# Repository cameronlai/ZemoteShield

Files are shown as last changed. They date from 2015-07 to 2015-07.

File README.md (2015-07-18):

# ZemoteShield
Zemote Shield for Zemote Universal Remote Control (on Arduino Uno and Nano)

This project, and all of its design files (including the layout), is licensed under the Creative Commons Attribution-ShareAlike 3.0 Unported license.

Related pages
- Project page: http://cameronlai.com/zemote/
- Zemote Firmware: https://github.com/cameronlai/ZemoteFirmware
- Zemote Host: https://github.com/cameronlai/ZemoteHost

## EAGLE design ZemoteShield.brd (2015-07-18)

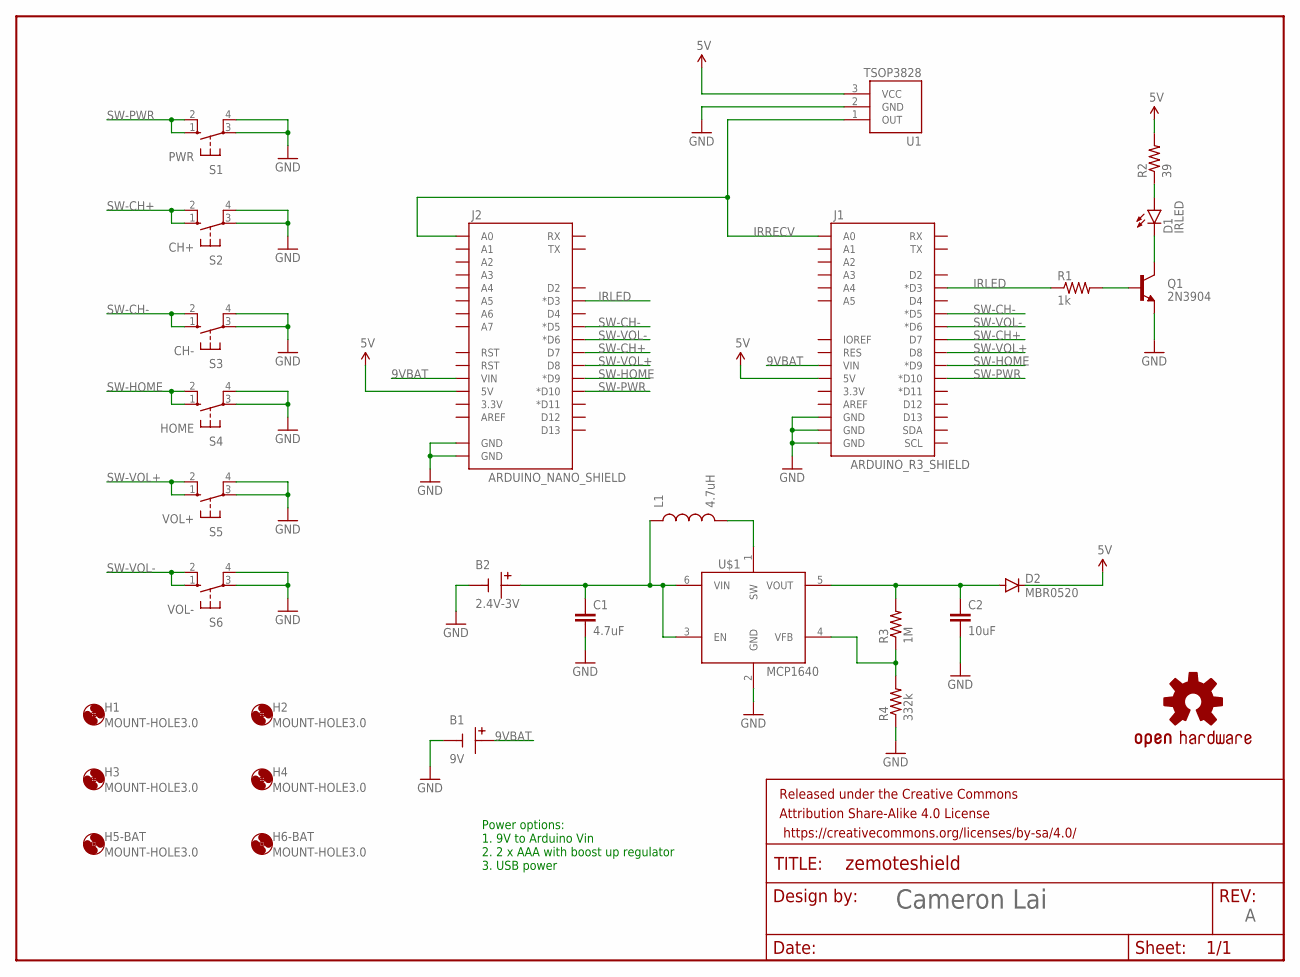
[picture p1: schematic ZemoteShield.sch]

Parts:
B1: 9V; BATTERY-2PIN-CON
B2: 2.4V-3V; BATTERY-2PIN-CON
C1: 4.7uF; 0603-CAP
C2: 10uF; 0805
D1: IRLED; LED5MM
D2: MBR0520; SOD-123
FRAME1: ZemoteShield; DUMMY
H1, H2, H3, H4, H5-BAT, H6-BAT: MOUNT-HOLE3.0; 3,0
J1: ARDUINO_R3_SHIELD; UNO_R3_SHIELD
J2: ARDUINO_NANO_SHIELD; NANO_SHIELD
L1: 4.7uH; 1210
LOGO1: OSHW-LOGOL; OSHW-LOGO-L
Q1: 2N3904; TO-92
R1: 1k; AXIAL-0.4
R2: 39; AXIAL-0.6
R3: 1M; 0603-RES
R4: 332k; 0603-RES
S1: PWR; B3F-10XX
S2: CH+; B3F-10XX
S3: CH-; B3F-10XX
S4: HOME; B3F-10XX
S5: VOL+; B3F-10XX
S6: VOL-; B3F-10XX
U1: TSOP3828; BRM-2508
U$1: MCP1640; SOT23-6

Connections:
5V: D2.C, J1.5V, J2.5V, R2.P$2 (2), U1.3 (VCC)
9VBAT: B1.POS, J1.VIN, J2.VIN
AAABAT: B2.POS, C1.1, L1.1, U$1.3 (EN), U$1.6 (VIN)
GND: B1.NEG, B2.NEG, C1.2, C2.2, J1.GND@0 (GND), J1.GND@1 (GND), J1.GND@2 (GND), J2.GND@0 (GND), J2.GND@1 (GND), Q1.1 (E), R4.1, S1.3, S1.4 (P1), S2.3, S2.4 (P1), S3.3, S3.4 (P1), S4.3, S4.4 (P1), S5.3, S5.4 (P1), S6.3, S6.4 (P1), U1.2 (GND), U$1.2 (GND)
IRLED: J1.D3 (*D3), J2.D3 (*D3), R1.P$1 (1)
IRRECV: J1.A0, J2.A0, U1.1 (OUT)
unnamed: D1.K (C), Q1.3 (C)
unnamed: Q1.2 (B), R1.P$2 (2)
unnamed: D1.A, R2.P$1 (1)
unnamed: L1.2, U$1.1 (SW)
unnamed: C2.1, D2.A, R3.2, U$1.5 (VOUT)
unnamed: R3.1, R4.2, U$1.4 (VFB)
SW-CH+: J1.D7, J2.D7, S2.1 (S), S2.2 (S1)
SW-CH-: J1.D5 (*D5), J2.D5 (*D5), S3.1 (S), S3.2 (S1)
SW-HOME: J1.D9 (*D9), J2.D9 (*D9), S4.1 (S), S4.2 (S1)
SW-PWR: J1.D10 (*D10), J2.D10 (*D10), S1.1 (S), S1.2 (S1)
SW-VOL+: J1.D8, J2.D8, S5.1 (S), S5.2 (S1)
SW-VOL-: J1.D6 (*D6), J2.D6 (*D6), S6.1 (S), S6.2 (S1)

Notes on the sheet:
Power options: 1. 9V to Arduino Vin 2. 2 x AAA with boost up regulator 3. USB power

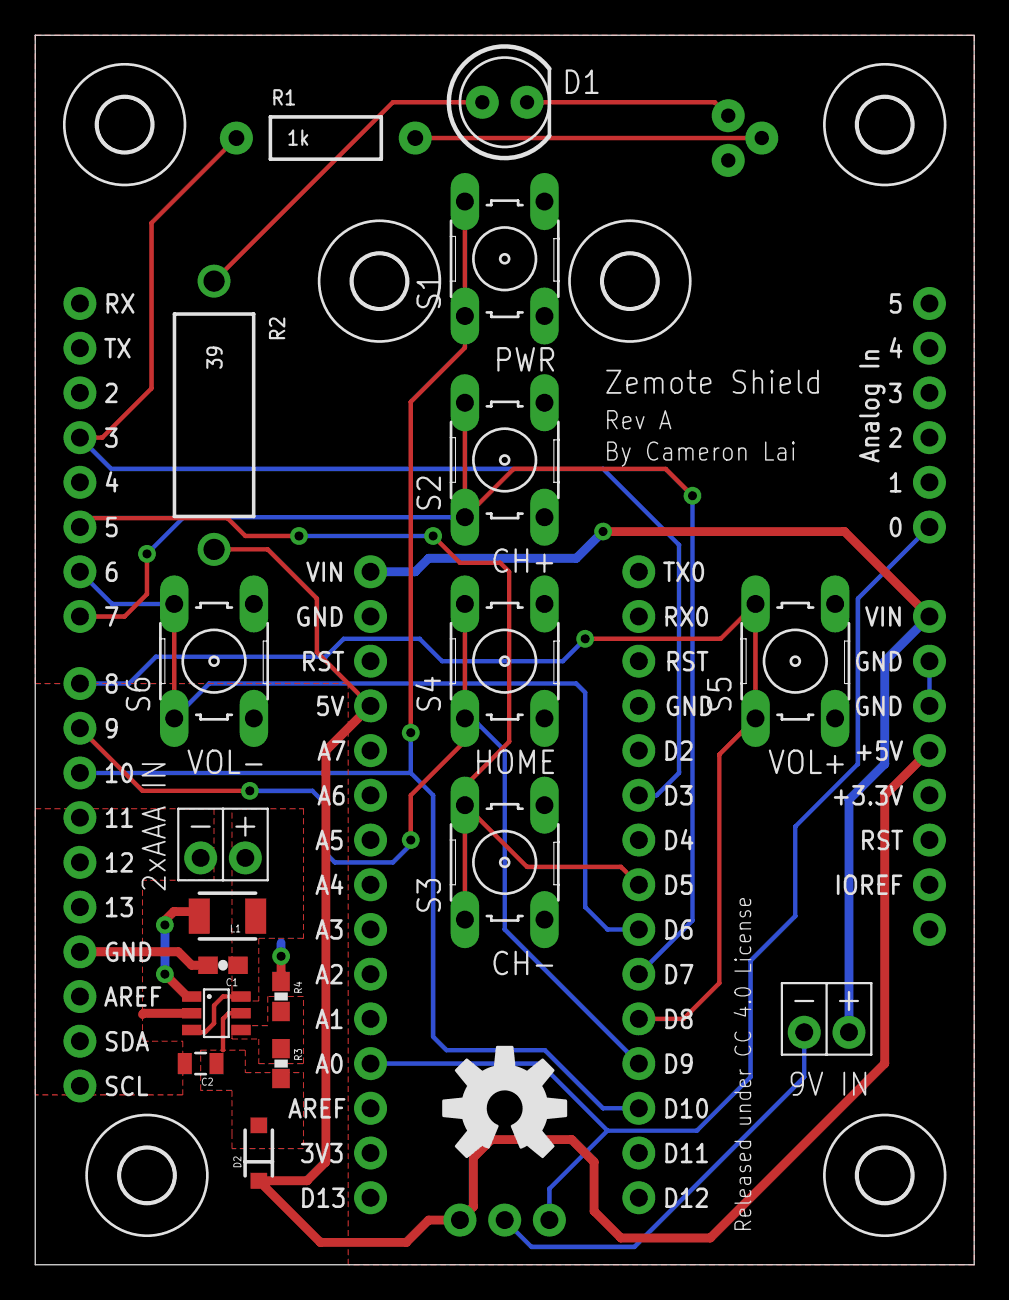
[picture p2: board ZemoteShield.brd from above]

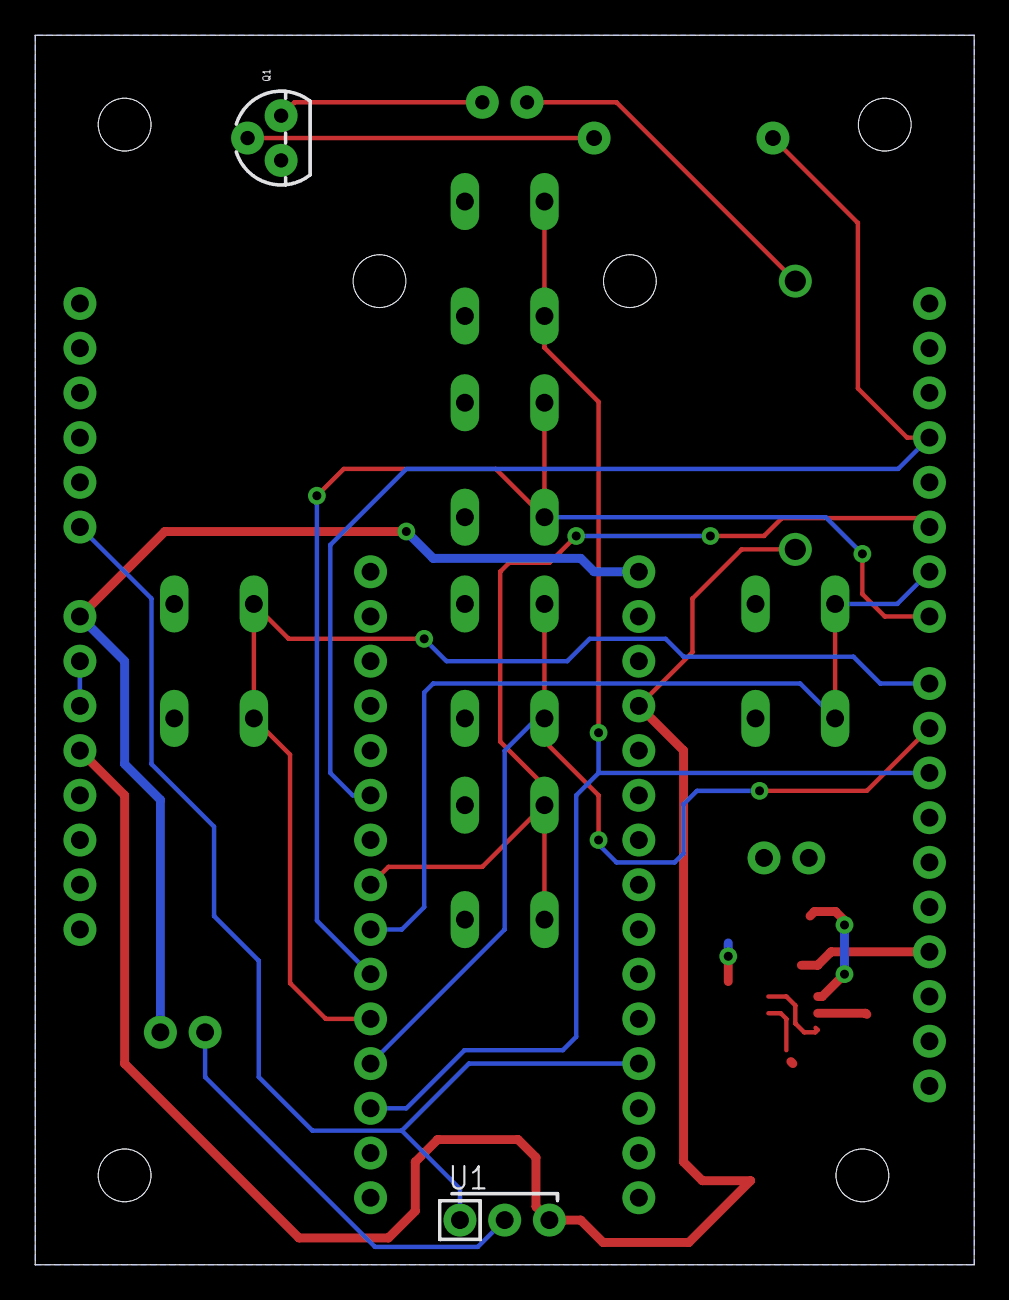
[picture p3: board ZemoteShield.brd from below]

Board: 2 copper layers, 53.3 x 69.8 mm, 30 parts (2 on the bottom side), 18 nets.

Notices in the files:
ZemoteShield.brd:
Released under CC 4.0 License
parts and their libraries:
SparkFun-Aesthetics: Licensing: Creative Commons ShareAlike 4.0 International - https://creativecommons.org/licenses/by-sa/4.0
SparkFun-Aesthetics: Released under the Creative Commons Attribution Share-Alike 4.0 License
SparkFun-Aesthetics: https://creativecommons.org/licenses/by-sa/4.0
